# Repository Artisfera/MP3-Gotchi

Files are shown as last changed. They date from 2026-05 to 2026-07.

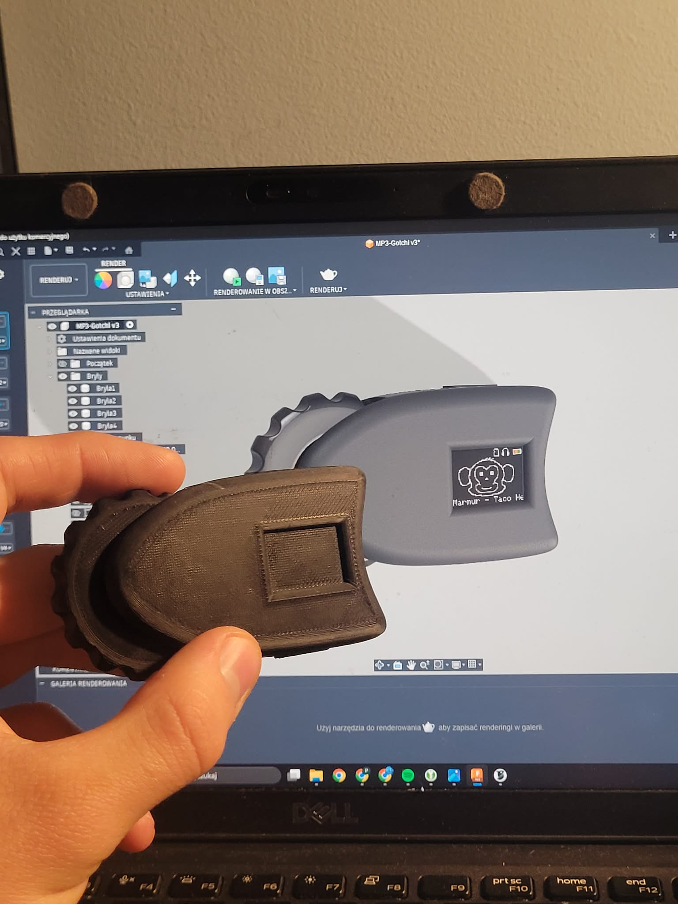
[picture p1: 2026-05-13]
hardware/3dmodels/0.1.0/Live-preview1-0.1.0.jpg

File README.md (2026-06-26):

# MP3-Gotchi

MP3-Gotchi is a tiny Tamagotchi-style offline MP3 player with a small monkey companion on a 96x64 color OLED.

The project is built around an ESP32, SSD1331 OLED, rotary encoder, YX5300 MP3 module, MPU6050 motion sensor, and haptic motor. It is shared as a community-source, source-available, non-commercial hardware and firmware project.

Current firmware release: `mp3gotchi-0.2.0`.

## Quick Start

Open the latest Arduino sketch here:

```text
firmware/src/mp3gotchi-0.2.0/mp3gotchi-0.2.0.ino
```

User-facing firmware settings live in:

```text
firmware/src/mp3gotchi-0.2.0/UserConfig.h
```

Start there for messages, track count, YX5300 track offset, volume, brightness, encoder steps, shake thresholds, and custom emote timing.

## Repository Layout

```text
firmware/assets/          Source sprite assets and sprite reference files.
firmware/src/             Latest Arduino sketch only.
firmware/reversions/      Historical firmware snapshots.
firmware/tools/           Community helper scripts for SD cards, fonts, and emotes.
firmware/user_emotes/     User workspace for custom emote layers.
hardware/3dmodels/        Enclosure exports by version.
hardware/drivers/         Driver download notes.
hardware/schematics/      Prototype schematic exports.
timelapses/               Prototype build videos and timelapse documentation.
```

## Firmware

The latest firmware uses:

- YX5300 UART playback,
- SSD1331 color OLED rendering,
- rotary encoder click and rotation controls,
- MPU6050 shake detection,
- haptic feedback,
- persistent ESP32 Preferences for track, volume, brightness, and shake settings,
- generated sparse RGB565 custom emotes,
- generated Aseprite Mini bitmap font data.

More firmware details are in `firmware/README.md` and the latest sketch README.

## Community Helpers

Prepare a YX5300 SD card in deterministic alphabetical copy order:

```powershell
python .\firmware\tools\prepare_yx5300_sd.py
```

Build custom emotes from full-screen PNG layers:

```powershell
py .\firmware\tools\user_emotes\build_user_emotes.py
```

Regenerate the Aseprite Mini font header from a local `.otf` file:

```powershell
python .\firmware\tools\generate_aseprite_mini_font.py --input C:\path\to\aseprite-mini.otf --output .\firmware\src\mp3gotchi-0.2.0\AsepriteMiniFontData.h --font-size 5
```

Local songs belong in `firmware/tools/songs/` while preparing an SD card. Real audio files are intentionally ignored by Git.

## Local Folders

`.git` is required by Git. It contains repository history, branches, and commit metadata. Do not delete it if you want commits to work.

`.venv` is a local Python virtual environment for helper scripts. It is useful on your machine but should not be committed.

`.backup` is local backup storage created during firmware work. It is ignored by Git.

## License and Use

MP3-Gotchi is shared for personal builds, learning, repair, modification, forks, and non-commercial community collaboration.

Commercial use is not allowed without written permission from Patryk Ankudowicz (Artisfera).

Because the project keeps a non-commercial restriction, it is not an OSI-approved open-source license. In public wording, prefer "community-source", "source-available", or "community-friendly non-commercial".

Firmware, helper scripts, and source code use the PolyForm Noncommercial License 1.0.0. Documentation, graphics, hardware files, models, schematics, videos, and media use CC BY-NC-SA 4.0 unless a file says otherwise. Third-party material is listed in `NOTICE`.

See `LICENSE` and `NON_COMMERCIAL_NOTICE.md`.

## AI Disclosure

Firmware and repository cleanup were prepared in collaboration with ChatGPT as a programming assistant.

The project concept, hardware direction, creative decisions, and authorship belong to Patryk Ankudowicz (Artisfera).

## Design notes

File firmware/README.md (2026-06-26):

# Firmware

The latest Arduino sketch is kept in `firmware/src/`.

For the current release, open:

```text
firmware/src/mp3gotchi-0.2.0/mp3gotchi-0.2.0.ino
```

Historical snapshots live in `firmware/reversions/`.

## Editing

Start with:

```text
firmware/src/mp3gotchi-0.2.0/UserConfig.h
```

This file is meant for community editing. It contains user-facing settings such as messages, default volume, brightness, track count, YX5300 index offset, encoder behavior, text scroll timing, shake thresholds, and custom emote timing.

Internal pin and firmware constants are kept in `ProjectConfig.h` and `PinMap.h`.

## Tools

- `tools/prepare_yx5300_sd.py` copies local songs to an SD card in deterministic alphabetical order.
- `tools/user_emotes/build_user_emotes.py` converts full-screen PNG layers into sparse RGB565 firmware assets.
- `tools/generate_aseprite_mini_font.py` generates the Aseprite Mini bitmap font header from a local `.otf` file.

Put local audio files in `tools/songs/` while preparing an SD card. The helper uses this folder by default no matter where it is launched from. The folder is ignored by Git except for its README.

## Arduino Libraries

Install these with Arduino IDE Library Manager:

- Adafruit SSD1331 OLED Driver Library
- Adafruit GFX Library

The MPU6050 is read through `Wire`.
The YX5300 module is controlled directly through UART frames.

## Versioning

`firmware/src/` contains the latest working sketch only.

`firmware/reversions/` keeps historical snapshots named like:

```text
mp3gotchi-0.1.13
mp3gotchi-0.2.0
```

The Arduino sketch folder name and `.ino` filename must match.

## License and Use

Firmware in this folder is part of MP3-Gotchi and follows the repository `LICENSE`.

It is community-source and source-available for personal building, learning, repair, modification, and non-commercial community collaboration.

Commercial use is not allowed without written permission from Patryk Ankudowicz (Artisfera).

Because the project keeps a non-commercial restriction, it is not OSI-approved open source. Prefer "community-source", "source-available", or "community-friendly non-commercial" in public wording.

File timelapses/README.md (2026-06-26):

# MP3-Gotchi Prototype Timelapses

This folder contains prototype build videos for MP3-Gotchi. They are documentation media for the project history and are not required to compile or flash the firmware.

Files:

- `1# MP3-Gotchi - Prototype 0.0.1.mp4`
- `2# MP3-Gotchi - Prototype.mp4`
- `3# MP3-Gotchi - Prototype.mp4`
- `4# MP3-Gotchi - Prototype.mp4`
- `5# MP3-Gotchi - Prototype.mp4`
- `6# MP3-Gotchi - Prototype.mp4`

Project concept, hardware direction, and authorship: Patryk Ankudowicz (Artisfera).

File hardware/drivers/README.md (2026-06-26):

# Drivers

Driver archives are not redistributed in this repository.

For CH341/CH340 USB-serial drivers, use the official WCH download page:

```text
https://www.wch-ic.com/downloads/CH341SER_EXE.html
```

This keeps third-party driver licensing separate from the MP3-Gotchi project license.

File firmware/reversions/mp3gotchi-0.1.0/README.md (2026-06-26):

# MP3-Gotchi firmware v0.1.0

This is the main firmware source for the MP3-Gotchi 0.1.0 prototype with a YX5300 audio module.
The code is meant to be copied into a project `src` folder and used as a clean base for later screens, tools, or small games.

## Features

- keeps `monkey-bg` as the static body/background layer,
- overlays face sprites for the normal and dizzy states,
- keeps the idle monkey visible when no special state is active,
- shows the dizzy face after a strong MPU6050 shake,
- pauses and resumes music with one encoder click,
- changes to the next track after the configured number of right encoder detents,
- restarts the current track on the first left action,
- moves to the previous track when the left action is repeated within the configured time window,
- enters ESP32 deep sleep after five encoder clicks,
- requires five clicks after a locked deep-sleep wake before the firmware starts playback again,
- can show a random weighted message in the bottom text strip after a track change.

## Arduino Libraries

Install these with Arduino IDE Library Manager:

- Adafruit SSD1331 OLED Driver Library
- Adafruit GFX Library
- Adafruit MPU6050
- Adafruit Unified Sensor

The YX5300 module is controlled directly through UART frames, so it does not need an external library.

## Pin Map

- OLED SCK: GPIO18
- OLED MOSI: GPIO23
- OLED RST: GPIO14
- OLED DC: GPIO13
- OLED CS: GPIO4
- YX5300 TX to ESP32 RX: GPIO17
- ESP32 TX to YX5300 RX through 1k: GPIO16
- Encoder A: GPIO27
- Encoder B: GPIO22
- Encoder SW: GPIO34, external 10k pull-up required
- Motor MOSFET gate: GPIO12
- MPU6050 SCL: GPIO5
- MPU6050 SDA: GPIO15
- MPU6050 INT: GPIO39
- Function 1 and Function 2 are reserved for future firmware and are not used in this version.

## Editing Bottom Messages

Edit the block in `MessagePool.cpp`:

```cpp
static const char MESSAGE_SCRIPT[] = R"MSG(
"Milego dnia!", 1.0;
"Dobry vibe", 0.8;
"Ziuu dalej", 0.7;
"Monkey mode", 1.2;
"Enjoy!";
"Shake me!", 0.5;
)MSG";
```

Format:

```cpp
"Text", 0.5;
"Text2";
"Text3", 1.2;
```

When no number is provided, the firmware uses weight `1.0`.
The number is a selection weight, not a percent. For example, `1.2` is more likely than `0.5`.

## Power Note

Five clicks do not physically disconnect the battery.
This firmware puts the ESP32 into deep sleep, tells the YX5300 to pause/sleep, blanks the OLED, and turns the motor output off.
A real hard power cut would need extra hardware such as a load switch, MOSFET latch, or physical switch.

## AI Disclosure

The `.ino` header intentionally says that the firmware was prepared in collaboration with ChatGPT as a programming assistant.
That note is part of the project process: the device concept, hardware decisions, and creative direction remain with the project author.

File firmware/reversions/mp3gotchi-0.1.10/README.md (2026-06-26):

# MP3-Gotchi firmware v0.1.10

This is the MP3-Gotchi 0.1.10 raw progress firmware. It keeps the working YX5300 and MPU6050 pinouts, adds logical YX5300 track mapping for the current module index offset, keeps user-generated emotes as generated sparse RGB565 assets, and keeps user-facing settings in one community-friendly file.

## Edit This First

Customize user settings in `UserConfig.h`.

That file contains:

- default YX5300 volume,
- default OLED brightness,
- logical YX5300 track count and module index offset,
- encoder detent thresholds,
- brightness encoder step,
- shake sensitivity,
- bottom text scroll speed,
- user emote timing and appearance chance,
- random bottom message chance,
- editable weighted message script.

## Features

- one click pauses/resumes playback,
- two clicks switches encoder mode between `Track`, `Volume`, and `Brightness`,
- five clicks enters ESP32 deep sleep,
- ten clicks resets playback to track 1,
- one encoder click wakes from deep sleep through GPIO34,
- track mode rotates through songs and keeps left-turn restart/previous behavior,
- volume mode changes YX5300 volume and saves it to ESP32 Preferences,
- brightness mode changes OLED brightness and saves it to ESP32 Preferences,
- Serial command `brightness 0-100` changes and saves OLED brightness,
- bottom messages scroll fully from offscreen left to offscreen right,
- bottom text is rendered with generated Aseprite Mini bitmap glyphs,
- custom user emotes can appear once per minute based on `UserConfig.h` chance settings,
- YX5300 finish events send the module `next` command instead of guessing a numeric track,
- MPU diagnostics default to the confirmed `SDA GPIO15 / SCL GPIO5` wiring,
- `mpu diag` prints 10 sensor samples over 10 seconds,
- `yx diag` prints raw module track and logical track mapping status.

## Font

The bottom text renderer uses `AsepriteMiniFontData.h`, generated from the real `aseprite-mini.otf` file supplied by the project author.
To regenerate it after replacing the font asset:

```powershell
.\.venv\Scripts\python.exe .\firmware\tools\generate_aseprite_mini_font.py --input C:\path\to\aseprite-mini.otf --output .\firmware\src\mp3gotchi-0.1.10\AsepriteMiniFontData.h --font-size 5
```

## Arduino Libraries

Install these with Arduino IDE Library Manager:

- Adafruit SSD1331 OLED Driver Library
- Adafruit GFX Library

The MPU6050 is read directly through `Wire`.
The YX5300 module is controlled directly through UART frames.

## Pin Map

- OLED SCK: GPIO18
- OLED MOSI: GPIO23
- OLED RST: GPIO14
- OLED DC: GPIO13
- OLED CS: GPIO4
- YX5300 TX to ESP32 RX: GPIO16
- ESP32 TX to YX5300 RX through 1k: GPIO17
- Encoder A: GPIO27
- Encoder B: GPIO22
- Encoder SW: GPIO34, external 10k pull-up required
- Motor MOSFET gate: GPIO12
- MPU6050 SDA: GPIO15
- MPU6050 SCL: GPIO5
- MPU6050 INT: GPIO39
- Function 1 and Function 2 are reserved for future firmware.

## Serial Commands

```text
pinout
brightness
brightness 0
brightness 50
brightness 100
mpu diag
yx diag
```

`mpu diag` reruns MPU detection and prints 10 accelerometer/gyro samples.
`yx diag` asks the module for current and total tracks, then prints raw module index, logical track, configured offset, and volume.

## Track Order

The ESP32 cannot alphabetically sort songs in this hardware layout because it talks only to the YX5300 over UART. It cannot see SD card filenames or directory entries.
Firmware uses YX5300 track commands and treats numeric track indexes as best-effort status only.

Normal next/previous navigation uses YX5300 module commands, because the module knows its own real track list and the ESP32 cannot read SD filenames through UART.
Absolute play commands use logical-to-module mapping from `UserConfig.h`.
With the current defaults, logical track `1` means file `001`, but the module command receives raw track index `2`.
If your module reports a different offset or track count, edit `USER_TRACK_COUNT` and `YX_TRACK_INDEX_OFFSET`.

## User Emotes

Put full-screen `96x64` PNG layers in `firmware/user_emotes/<emote-name>/`.
Use simple alphabetical prefixes when layer order matters:

```text
firmware/user_emotes/happy/
  01-eyes.png
  02-mouth.png
  03-nose.png
```

Run:

```powershell
py .\firmware\tools\user_emotes\build_user_emotes.py
```

The tool lists detected emote folders, asks which ones to build, asks for each emote weight and duration, writes `emote.png` previews, and generates `UserEmotes.h` in the latest sketch folder.
PNG is only the host-side input and preview format. The ESP32 firmware uses generated sparse RGB565 pixel data from `UserEmotes.h`.
Black pixels and transparent pixels are treated as empty space, matching the source sprite workflow.
Global timing and chance are in `UserConfig.h`:

```cpp
USER_EMOTE_APPEAR_CHANCE_PERCENT
USER_EMOTE_ROLL_INTERVAL_MS
USER_EMOTE_DEFAULT_SHOW_MS
```

For deterministic SD copy order, put your audio files in `firmware/tools/songs`, then run the friendly helper:

```powershell
python .\firmware\tools\prepare_yx5300_sd.py
```

It lists available drives with their size, asks you to pick the SD card by number, and then copies songs alphabetically.

## Power Note

Five clicks do not physically disconnect the battery.
This firmware puts the ESP32 into deep sleep, tells the YX5300 to pause/sleep, blanks the OLED, and turns the motor output off.
A real hard power cut needs extra hardware such as a load switch, MOSFET latch, or physical switch.

## License and Use

This project is community-friendly and source-available for personal, educational, repair, modification, and non-commercial collaboration.
Commercial use is not allowed without written permission from Patryk Ankudowicz (Artisfera).

See the repository `LICENSE` and `NON_COMMERCIAL_NOTICE.md`.

## AI Disclosure

The `.ino` header intentionally says that the firmware was prepared in collaboration with ChatGPT as a programming assistant.
The device concept, hardware decisions, and creative direction remain with the project author.

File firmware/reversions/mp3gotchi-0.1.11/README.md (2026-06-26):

# MP3-Gotchi firmware v0.1.11

This is the MP3-Gotchi 0.1.11 raw progress firmware. It keeps the working YX5300 and MPU6050 pinouts, keeps logical YX5300 track mapping, adds simple 1-100 shake sensitivity control, uses software OLED brightness scaling, and keeps user-facing settings in one community-friendly file.

## Edit This First

Customize user settings in `UserConfig.h`.

That file contains:

- default YX5300 volume,
- default OLED brightness,
- logical YX5300 track count and module index offset,
- encoder detent thresholds,
- brightness encoder step,
- shake sensitivity,
- bottom text scroll speed,
- user emote timing and appearance chance,
- random bottom message chance,
- editable weighted message script.

## Features

- one click pauses/resumes playback,
- two clicks switches encoder mode between `Track`, `Volume`, and `Brightness`,
- five clicks enters ESP32 deep sleep,
- ten clicks resets playback to track 1,
- one encoder click wakes from deep sleep through GPIO34,
- track mode rotates through songs and keeps left-turn restart/previous behavior,
- volume mode changes YX5300 volume and saves it to ESP32 Preferences,
- brightness mode changes OLED brightness and saves it to ESP32 Preferences,
- Serial command `brightness 0-100` changes and saves OLED brightness,
- Serial command `shake 1-100` changes and saves MPU6050 shake sensitivity,
- duplicated YX5300 track-finished packets are ignored so automatic playback does not skip every second track,
- bottom messages scroll fully from offscreen left to offscreen right,
- bottom text is rendered with generated Aseprite Mini bitmap glyphs,
- custom user emotes can appear once per minute based on `UserConfig.h` chance settings,
- YX5300 finish events send the module `next` command instead of guessing a numeric track,
- MPU diagnostics default to the confirmed `SDA GPIO15 / SCL GPIO5` wiring,
- `mpu diag` prints 10 sensor samples over 10 seconds,
- `yx diag` prints raw module track and logical track mapping status.

## Font

The bottom text renderer uses `AsepriteMiniFontData.h`, generated from the real `aseprite-mini.otf` file supplied by the project author.
To regenerate it after replacing the font asset:

```powershell
.\.venv\Scripts\python.exe .\firmware\tools\generate_aseprite_mini_font.py --input C:\path\to\aseprite-mini.otf --output .\firmware\src\mp3gotchi-0.1.11\AsepriteMiniFontData.h --font-size 5
```

## Arduino Libraries

Install these with Arduino IDE Library Manager:

- Adafruit SSD1331 OLED Driver Library
- Adafruit GFX Library

The MPU6050 is read directly through `Wire`.
The YX5300 module is controlled directly through UART frames.

## Pin Map

- OLED SCK: GPIO18
- OLED MOSI: GPIO23
- OLED RST: GPIO14
- OLED DC: GPIO13
- OLED CS: GPIO4
- YX5300 TX to ESP32 RX: GPIO16
- ESP32 TX to YX5300 RX through 1k: GPIO17
- Encoder A: GPIO27
- Encoder B: GPIO22
- Encoder SW: GPIO34, external 10k pull-up required
- Motor MOSFET gate: GPIO12
- MPU6050 SDA: GPIO15
- MPU6050 SCL: GPIO5
- MPU6050 INT: GPIO39
- Function 1 and Function 2 are reserved for future firmware.

## Serial Commands

```text
pinout
brightness
brightness 0
brightness 50
brightness 100
shake
shake 35
shake 80
mpu diag
yx diag
```

`brightness 0-100` changes the rendered pixel brightness and persists it.
`shake 1-100` changes shake sensitivity and persists it. `1` needs a hard shake, `100` reacts to light movement.
`mpu diag` reruns MPU detection and prints 10 accelerometer/gyro samples.
`yx diag` asks the module for current and total tracks, then prints raw module index, logical track, configured offset, and volume.

## Track Order

The ESP32 cannot alphabetically sort songs in this hardware layout because it talks only to the YX5300 over UART. It cannot see SD card filenames or directory entries.
Firmware uses YX5300 track commands and treats numeric track indexes as best-effort status only.

Normal next/previous navigation uses YX5300 module commands, because the module knows its own real track list and the ESP32 cannot read SD filenames through UART.
Absolute play commands use logical-to-module mapping from `UserConfig.h`.
With the current defaults, logical track `1` means file `001`, but the module command receives raw track index `2`.
If your module reports a different offset or track count, edit `USER_TRACK_COUNT` and `YX_TRACK_INDEX_OFFSET`.

## User Emotes

Put full-screen `96x64` PNG layers in `firmware/user_emotes/<emote-name>/`.
Use simple alphabetical prefixes when layer order matters:

```text
firmware/user_emotes/happy/
  01-eyes.png
  02-mouth.png
  03-nose.png
```

Run:

```powershell
py .\firmware\tools\user_emotes\build_user_emotes.py
```

The tool lists detected emote folders, asks which ones to build, asks for each emote weight and duration, writes `emote.png` previews, and generates `UserEmotes.h` in the latest sketch folder.
PNG is only the host-side input and preview format. The ESP32 firmware uses generated sparse RGB565 pixel data from `UserEmotes.h`.
Black pixels and transparent pixels are treated as empty space, matching the source sprite workflow.
Global timing and chance are in `UserConfig.h`:

```cpp
USER_EMOTE_APPEAR_CHANCE_PERCENT
USER_EMOTE_ROLL_INTERVAL_MS
USER_EMOTE_DEFAULT_SHOW_MS
```

For deterministic SD copy order, put your audio files in `firmware/tools/songs`, then run the friendly helper:

```powershell
python .\firmware\tools\prepare_yx5300_sd.py
```

It lists available drives with their size, asks you to pick the SD card by number, and then copies songs alphabetically.

## Power Note

Five clicks do not physically disconnect the battery.
This firmware puts the ESP32 into deep sleep, tells the YX5300 to pause/sleep, blanks the OLED, and turns the motor output off.
A real hard power cut needs extra hardware such as a load switch, MOSFET latch, or physical switch.

## License and Use

This project is community-friendly and source-available for personal, educational, repair, modification, and non-commercial collaboration.
Commercial use is not allowed without written permission from Patryk Ankudowicz (Artisfera).

See the repository `LICENSE` and `NON_COMMERCIAL_NOTICE.md`.

## AI Disclosure

The `.ino` header intentionally says that the firmware was prepared in collaboration with ChatGPT as a programming assistant.
The device concept, hardware decisions, and creative direction remain with the project author.

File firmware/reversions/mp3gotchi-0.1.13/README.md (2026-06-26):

# MP3-Gotchi firmware v0.1.13

This is the MP3-Gotchi 0.1.13 raw progress firmware. It keeps the working YX5300 and MPU6050 pinouts, keeps logical YX5300 track mapping, replaces the old artificial shake sensitivity scale with real MPU6050 thresholds, uses software OLED brightness scaling, and keeps user-facing settings in one community-friendly file.

## Edit This First

Customize user settings in `UserConfig.h`.

That file contains:

- default YX5300 volume,
- default OLED brightness,
- logical YX5300 track count and module index offset,
- encoder detent thresholds,
- brightness encoder step,
- shake detection thresholds,
- bottom text scroll speed,
- user emote timing and appearance chance,
- random bottom message chance,
- editable weighted message script.

## Features

- one click pauses/resumes playback,
- two clicks switches encoder mode between `Track`, `Volume`, and `Brightness`,
- five clicks enters ESP32 deep sleep,
- ten clicks resets playback to track 1,
- one encoder click wakes from deep sleep through GPIO34,
- track mode rotates through songs and keeps left-turn restart/previous behavior,
- volume mode changes YX5300 volume and saves it to ESP32 Preferences,
- brightness mode changes OLED brightness and saves it to ESP32 Preferences,
- Serial command `brightness 0-100` changes and saves OLED brightness,
- Serial command `shake` prints MPU6050 shake settings,
- Serial commands `shake hard`, `shake normal`, `shake light`, `shake verylight`, `shake off`, and `shake on` change and save shake profiles,
- Serial commands `shake total`, `shake change`, `shake gyro`, `shake confirm`, and `shake cooldown` fine tune shake detection and save it,
- Serial command `reboot` restarts the ESP32 firmware,
- duplicated YX5300 track-finished packets are ignored so automatic playback does not skip every second track,
- bottom text scroll updates only changed pixels to avoid visible blinking,
- bottom messages scroll fully from offscreen left to offscreen right,
- bottom text is rendered with generated Aseprite Mini bitmap glyphs,
- custom user emotes can appear once per minute based on `UserConfig.h` chance settings,
- YX5300 finish events send the module `next` command instead of guessing a numeric track,
- MPU diagnostics default to the confirmed `SDA GPIO15 / SCL GPIO5` wiring,
- `mpu diag` prints 10 sensor samples over 10 seconds,
- `yx diag` prints raw module track and logical track mapping status.

## Font

The bottom text renderer uses `AsepriteMiniFontData.h`, generated from the real `aseprite-mini.otf` file supplied by the project author.
To regenerate it after replacing the font asset:

```powershell
.\.venv\Scripts\python.exe .\firmware\tools\generate_aseprite_mini_font.py --input C:\path\to\aseprite-mini.otf --output .\firmware\src\mp3gotchi-0.1.13\AsepriteMiniFontData.h --font-size 5
```

## Arduino Libraries

Install these with Arduino IDE Library Manager:

- Adafruit SSD1331 OLED Driver Library
- Adafruit GFX Library

The MPU6050 is read directly through `Wire`.
The YX5300 module is controlled directly through UART frames.

## Pin Map

- OLED SCK: GPIO18
- OLED MOSI: GPIO23
- OLED RST: GPIO14
- OLED DC: GPIO13
- OLED CS: GPIO4
- YX5300 TX to ESP32 RX: GPIO16
- ESP32 TX to YX5300 RX through 1k: GPIO17
- Encoder A: GPIO27
- Encoder B: GPIO22
- Encoder SW: GPIO34, external 10k pull-up required
- Motor MOSFET gate: GPIO12
- MPU6050 SDA: GPIO15
- MPU6050 SCL: GPIO5
- MPU6050 INT: GPIO39
- Function 1 and Function 2 are reserved for future firmware.

## Serial Commands

```text
pinout
brightness
brightness 0
brightness 50
brightness 100
shake
shake hard
shake normal
shake light
shake verylight
shake off
shake on
shake total 0.85
shake change 0.50
shake gyro 360
shake confirm 2
shake cooldown 900
reboot
mpu diag
yx diag
```

`brightness 0-100` changes the rendered pixel brightness and persists it.
`shake` prints the current MPU6050 shake thresholds and command help.
The named shake profiles persist to flash. `hard` needs a very deliberate shake, `normal` is the default, `light` is easier, and `verylight` is intentionally sensitive.
Custom shake commands persist too:

- `shake total <g>` sets how far total acceleration must move away from normal gravity,
- `shake change <g>` sets the required frame-to-frame acceleration change,
- `shake gyro <dps>` sets the required rotation speed,
- `shake confirm <1-10>` sets how many consecutive strong samples are required,
- `shake cooldown <ms>` sets the delay after a detected shake.

`reboot` restarts the ESP32 firmware with `ESP.restart()`.
`mpu diag` reruns MPU detection and prints 10 accelerometer/gyro samples.
`yx diag` asks the module for current and total tracks, then prints raw module index, logical track, configured offset, and volume.

## Track Order

The ESP32 cannot alphabetically sort songs in this hardware layout because it talks only to the YX5300 over UART. It cannot see SD card filenames or directory entries.
Firmware uses YX5300 track commands and treats numeric track indexes as best-effort status only.

Normal next/previous navigation uses YX5300 module commands, because the module knows its own real track list and the ESP32 cannot read SD filenames through UART.
Absolute play commands use logical-to-module mapping from `UserConfig.h`.
With the current defaults, logical track `1` means file `001`, but the module command receives raw track index `2`.
If your module reports a different offset or track count, edit `USER_TRACK_COUNT` and `YX_TRACK_INDEX_OFFSET`.

## User Emotes

Put full-screen `96x64` PNG layers in `firmware/user_emotes/<emote-name>/`.
Use simple alphabetical prefixes when layer order matters:

```text
firmware/user_emotes/happy/
  01-eyes.png
  02-mouth.png
  03-nose.png
```

Run:

```powershell
py .\firmware\tools\user_emotes\build_user_emotes.py
```

The tool lists detected emote folders, asks which ones to build, asks for each emote weight and duration, writes `emote.png` previews, and generates `UserEmotes.h` in the latest sketch folder.
PNG is only the host-side input and preview format. The ESP32 firmware uses generated sparse RGB565 pixel data from `UserEmotes.h`.
Black pixels and transparent pixels are treated as empty space, matching the source sprite workflow.
Global timing and chance are in `UserConfig.h`:

```cpp
USER_EMOTE_APPEAR_CHANCE_PERCENT
USER_EMOTE_ROLL_INTERVAL_MS
USER_EMOTE_DEFAULT_SHOW_MS
```

For deterministic SD copy order, put your audio files in `firmware/tools/songs`, then run the friendly helper:

```powershell
python .\firmware\tools\prepare_yx5300_sd.py
```

It lists available drives with their size, asks you to pick the SD card by number, and then copies songs alphabetically.

## Power Note

Five clicks do not physically disconnect the battery.
This firmware puts the ESP32 into deep sleep, tells the YX5300 to pause/sleep, blanks the OLED, and turns the motor output off.
A real hard power cut needs extra hardware such as a load switch, MOSFET latch, or physical switch.

## License and Use

This project is community-friendly and source-available for personal, educational, repair, modification, and non-commercial collaboration.
Commercial use is not allowed without written permission from Patryk Ankudowicz (Artisfera).

See the repository `LICENSE` and `NON_COMMERCIAL_NOTICE.md`.

## AI Disclosure

The `.ino` header intentionally says that the firmware was prepared in collaboration with ChatGPT as a programming assistant.
The device concept, hardware decisions, and creative direction remain with the project author.

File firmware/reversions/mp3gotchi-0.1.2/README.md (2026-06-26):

# MP3-Gotchi firmware v0.1.2

This is the main firmware source for the MP3-Gotchi 0.1.2 prototype with a YX5300 audio module.
The code is meant to be copied into a project `src` folder and used as a clean base for later screens, tools, or small games.

## Features

- keeps `monkey-bg` as the static body/background layer,
- overlays face sprites for the normal and dizzy states,
- keeps the idle monkey visible when no special state is active,
- shows the dizzy face after a strong MPU6050 shake,
- pauses and resumes music with one encoder click,
- changes to the next track after the configured number of right encoder detents,
- restarts the current track on the first left action,
- moves to the previous track when the left action is repeated within the configured time window,
- enters ESP32 deep sleep after five encoder clicks,
- can show a random weighted message in the bottom text strip after a track change.
- includes temporary Serial Monitor pinout debug commands for MPU6050 and YX5300 wiring checks.

## Arduino Libraries

Install these with Arduino IDE Library Manager:

- Adafruit SSD1331 OLED Driver Library
- Adafruit GFX Library
- Adafruit MPU6050
- Adafruit Unified Sensor

The YX5300 module is controlled directly through UART frames, so it does not need an external library.

## Pin Map

- OLED SCK: GPIO18
- OLED MOSI: GPIO23
- OLED RST: GPIO14
- OLED DC: GPIO13
- OLED CS: GPIO4
- YX5300 TX to ESP32 RX: GPIO16
- ESP32 TX to YX5300 RX through 1k: GPIO17
- Encoder A: GPIO27
- Encoder B: GPIO22
- Encoder SW: GPIO34, external 10k pull-up required
- Motor MOSFET gate: GPIO12
- MPU6050 SDA: GPIO5
- MPU6050 SCL: GPIO15
- MPU6050 INT: GPIO39
- Function 1 and Function 2 are reserved for future firmware and are not used in this version.

## Editing Bottom Messages

Edit the block in `MessagePool.cpp`:

```cpp
static const char MESSAGE_SCRIPT[] = R"MSG(
"Milego dnia!", 1.0;
"Dobry vibe", 0.8;
"Ziuu dalej", 0.7;
"Monkey mode", 1.2;
"Enjoy!";
"Shake me!", 0.5;
)MSG";
```

Format:

```cpp
"Text", 0.5;
"Text2";
"Text3", 1.2;
```

When no number is provided, the firmware uses weight `1.0`.
The number is a selection weight, not a percent. For example, `1.2` is more likely than `0.5`.

## Power Note

Five clicks do not physically disconnect the battery.
This firmware puts the ESP32 into deep sleep, tells the YX5300 to pause/sleep, blanks the OLED, and turns the motor output off.
A real hard power cut would need extra hardware such as a load switch, MOSFET latch, or physical switch.

## Temporary Pinout Debug Commands

These Serial Monitor commands are temporary and should be removed after the hardware pinout is confirmed:

```text
pinout
odwroc mpu
odwroc yx
odwroc mpu/yx
```

`odwroc mpu` swaps SDA/SCL between `5/15` and `15/5`, then reruns MPU init.
`odwroc yx` swaps RX/TX between `16/17` and `17/16`, then sends volume plus play track 1.

## AI Disclosure

The `.ino` header intentionally says that the firmware was prepared in collaboration with ChatGPT as a programming assistant.
That note is part of the project process: the device concept, hardware decisions, and creative direction remain with the project author.

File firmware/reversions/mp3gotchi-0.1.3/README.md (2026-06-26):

# MP3-Gotchi firmware v0.1.3

This is the main firmware source for the MP3-Gotchi 0.1.3 prototype with a YX5300 audio module.
The code is meant to be copied into a project `src` folder and used as a clean base for later screens, tools, or small games.

## Features

- keeps `monkey-bg` as the static body/background layer,
- overlays face sprites for the normal and dizzy states,
- keeps the idle monkey visible when no special state is active,
- shows the dizzy face after a strong MPU6050 shake,
- pauses and resumes music with one encoder click,
- changes to the next track after the configured number of right encoder detents,
- restarts the current track on the first left action,
- moves to the previous track when the left action is repeated within the configured time window,
- enters ESP32 deep sleep after five encoder clicks,
- resets playback to track 1 after ten encoder clicks,
- remembers the last estimated track in ESP32 preferences before deep sleep,
- advances playback when the YX5300 reports that the current track ended,
- can show a random weighted message in the bottom text strip after a track change.
- includes temporary Serial Monitor pinout debug commands for MPU6050 and YX5300 wiring checks.

## Arduino Libraries

Install these with Arduino IDE Library Manager:

- Adafruit SSD1331 OLED Driver Library
- Adafruit GFX Library
- Adafruit MPU6050
- Adafruit Unified Sensor

The YX5300 module is controlled directly through UART frames, so it does not need an external library.
Playback uses global track numbers instead of folder-specific `001.mp3` naming rules.

## Pin Map

- OLED SCK: GPIO18
- OLED MOSI: GPIO23
- OLED RST: GPIO14
- OLED DC: GPIO13
- OLED CS: GPIO4
- YX5300 TX to ESP32 RX: GPIO16
- ESP32 TX to YX5300 RX through 1k: GPIO17
- Encoder A: GPIO27
- Encoder B: GPIO22
- Encoder SW: GPIO34, external 10k pull-up required
- Motor MOSFET gate: GPIO12
- MPU6050 SDA: GPIO5
- MPU6050 SCL: GPIO15
- MPU6050 INT: GPIO39
- Function 1 and Function 2 are reserved for future firmware and are not used in this version.

## Editing Bottom Messages

Edit the block in `MessagePool.cpp`:

```cpp
static const char MESSAGE_SCRIPT[] = R"MSG(
"Milego dnia!", 1.0;
"Dobry vibe", 0.8;
"Ziuu dalej", 0.7;
"Monkey mode", 1.2;
"Enjoy!";
"Shake me!", 0.5;
)MSG";
```

Format:

```cpp
"Text", 0.5;
"Text2";
"Text3", 1.2;
```

When no number is provided, the firmware uses weight `1.0`.
The number is a selection weight, not a percent. For example, `1.2` is more likely than `0.5`.

## Power Note

Five clicks do not physically disconnect the battery.
This firmware puts the ESP32 into deep sleep, tells the YX5300 to pause/sleep, blanks the OLED, and turns the motor output off.
A real hard power cut would need extra hardware such as a load switch, MOSFET latch, or physical switch.

## Temporary Pinout Debug Commands

These Serial Monitor commands are temporary and should be removed after the hardware pinout is confirmed:

```text
pinout
odwroc mpu
odwroc yx
odwroc mpu/yx
```

`odwroc mpu` swaps SDA/SCL between `5/15` and `15/5`, then reruns MPU init.
`odwroc yx` swaps RX/TX between `16/17` and `17/16`, then sends volume plus play track 1.
MPU init also auto-detects both pin orders and addresses `0x68` / `0x69`.

## Font

The bottom text strip uses an Aseprite Mini-compatible 3x5 bitmap renderer at 5 px height.

## AI Disclosure

The `.ino` header intentionally says that the firmware was prepared in collaboration with ChatGPT as a programming assistant.
That note is part of the project process: the device concept, hardware decisions, and creative direction remain with the project author.

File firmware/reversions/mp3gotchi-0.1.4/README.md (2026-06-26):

# MP3-Gotchi firmware v0.1.4

This is the MP3-Gotchi 0.1.4 raw progress firmware. It keeps the tested 0.1.3 behavior, leaves the working YX5300 pinout unchanged, and replaces the MPU6050 library path with a direct I2C driver that prints exact init stages.

## Features

- keeps `monkey-bg` as the static body/background layer,
- overlays normal and dizzy face sprites,
- pauses and resumes music with one encoder click,
- changes to the next track after the configured number of right encoder detents,
- restarts the current track on the first left action,
- moves to the previous track when the left action is repeated within the configured time window,
- waits for the full multi-click window so 10 clicks reset track 1 and do not trigger 5-click sleep,
- enters ESP32 deep sleep after five clicks,
- remembers the last estimated track before deep sleep,
- resumes the saved track after wake,
- resets and saves track 1 after ten clicks,
- uses raw MPU6050 I2C reads for shake detection,
- sends YX5300 loop-all fallback on boot and still logs finish packets if they arrive,
- scrolls the bottom message strip from left to right.

## Arduino Libraries

Install these with Arduino IDE Library Manager:

- Adafruit SSD1331 OLED Driver Library
- Adafruit GFX Library

The MPU6050 is read directly through `Wire`, so this version does not need the Adafruit MPU6050 or Adafruit Unified Sensor libraries.
The YX5300 module is controlled directly through UART frames, so it does not need an external audio library.

## Pin Map

- OLED SCK: GPIO18
- OLED MOSI: GPIO23
- OLED RST: GPIO14
- OLED DC: GPIO13
- OLED CS: GPIO4
- YX5300 TX to ESP32 RX: GPIO16
- ESP32 TX to YX5300 RX through 1k: GPIO17
- Encoder A: GPIO27
- Encoder B: GPIO22
- Encoder SW: GPIO34, external 10k pull-up required
- Motor MOSFET gate: GPIO12
- MPU6050 SDA: GPIO5
- MPU6050 SCL: GPIO15
- MPU6050 INT: GPIO39
- Function 1 and Function 2 are reserved for future firmware and are not used in this version.

## MPU6050 Debug

On boot the firmware tries both pin orders and both common MPU addresses:

- SDA GPIO5 / SCL GPIO15, addresses `0x68` and `0x69`
- SDA GPIO15 / SCL GPIO5, addresses `0x68` and `0x69`

For each attempt it reads `WHO_AM_I`, accepts `0x68`, `0x70`, and `0x71`, writes `PWR_MGMT_1 = 0x00`, and then reads raw accel/gyro bytes from `0x3B`.
Serial output names the exact failed stage: `address`, `WHO_AM_I`, `wake`, or `read sample`.

## Temporary Serial Commands

These commands are temporary and should be removed after the hardware pinout and YX behavior are confirmed:

```text
pinout
odwroc mpu
odwroc yx
odwroc mpu/yx
loop all on
loop all off
```

`odwroc mpu` swaps SDA/SCL between `5/15` and `15/5`, then reruns MPU init.
`odwroc yx` swaps RX/TX between `16/17` and `17/16`, then sends volume plus play track 1.
`loop all on` and `loop all off` send the YX5300 repeat-all fallback command.

## Track Order

The ESP32 cannot alphabetically sort songs in this hardware layout because it talks only to the YX5300 over UART. It cannot see SD card filenames or directory entries.
Firmware therefore uses global YX5300 track indexes.

For alphabetical playback without requiring `001`, `002`, `003` names, prepare an empty SD card from a sorted source folder:

```powershell
.\firmware\tools\prepare_yx5300_sd.ps1 -Source C:\Music\MP3Gotchi -Destination E:\
```

If your module or card still behaves unpredictably, use the stronger optional copy mode:

```powershell
.\firmware\tools\prepare_yx5300_sd.ps1 -Source C:\Music\MP3Gotchi -Destination E:\ -PrefixNumeric
```

The helper copies files one by one in alphabetical source order. Most YX5300-style modules play according to FAT directory order, so the SD card should be empty before copying.

## Editing Bottom Messages

Edit the block in `MessagePool.cpp`:

```cpp
static const char MESSAGE_SCRIPT[] = R"MSG(
"Milego dnia!", 1.0;
"Dobry vibe", 0.8;
"Ziuu dalej", 0.7;
"Monkey mode", 1.2;
"Enjoy!";
"Shake me!", 0.5;
)MSG";
```

Format:

```cpp
"Text", 0.5;
"Text2";
"Text3", 1.2;
```

When no number is provided, the firmware uses weight `1.0`.
The number is a selection weight, not a percent. For example, `1.2` is more likely than `0.5`.

## Font

The current firmware still contains `TinyFont5` as a temporary fallback so the sketch stays buildable.
It is not claimed to be Aseprite Mini.

To use the real Aseprite Mini font, supply your own licensed PNG sheet and generate a header named `AsepriteMiniFontData.h`:

```powershell
python .\firmware\tools\generate_aseprite_mini_font.py --input C:\Fonts\aseprite-mini.png --output .\firmware\src\mp3gotchi-0.1.4\AsepriteMiniFontData.h
```

After the generated header is available, replace the fallback renderer with the generated glyph table.

## Power Note

Five clicks do not physically disconnect the battery.
This firmware puts the ESP32 into deep sleep, tells the YX5300 to pause/sleep, blanks the OLED, and turns the motor output off.
A real hard power cut would need extra hardware such as a load switch, MOSFET latch, or physical switch.

## AI Disclosure

The `.ino` header intentionally says that the firmware was prepared in collaboration with ChatGPT as a programming assistant.
That note is part of the project process: the device concept, hardware decisions, and creative direction remain with the project author.

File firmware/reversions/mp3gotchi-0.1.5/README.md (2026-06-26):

# MP3-Gotchi firmware v0.1.5

This is the MP3-Gotchi 0.1.5 raw progress firmware. It keeps the working YX5300 UART pinout, adds stronger MPU6050 diagnostics, fixes end-of-track playback, adds OLED brightness control, and moves user-facing settings into one community-friendly file.

## Edit This First

Customize user settings in `UserConfig.h`.

That file contains:

- default YX5300 volume,
- default OLED brightness,
- known track count for wrap-to-track-1,
- encoder detent thresholds,
- bottom text scroll speed,
- random bottom message chance,
- editable weighted message script.

## Features

- one click pauses/resumes playback,
- two clicks switches encoder mode between `TRACK` and `VOLUME`,
- five clicks enters ESP32 deep sleep,
- ten clicks resets playback to track 1,
- one encoder click wakes from deep sleep through GPIO34,
- track mode rotates through songs and keeps left-turn restart/previous behavior,
- volume mode changes YX5300 volume and saves it to ESP32 Preferences,
- Serial command `brightness 0-100` changes and saves OLED brightness,
- bottom messages scroll fully from offscreen left to offscreen right,
- YX5300 finish events explicitly start the next track,
- MPU diagnostics try both pin orders, addresses `0x68/0x69`, and I2C speeds `100k/50k/400k`.

## Arduino Libraries

Install these with Arduino IDE Library Manager:

- Adafruit SSD1331 OLED Driver Library
- Adafruit GFX Library

The MPU6050 is read directly through `Wire`.
The YX5300 module is controlled directly through UART frames.

## Pin Map

- OLED SCK: GPIO18
- OLED MOSI: GPIO23
- OLED RST: GPIO14
- OLED DC: GPIO13
- OLED CS: GPIO4
- YX5300 TX to ESP32 RX: GPIO16
- ESP32 TX to YX5300 RX through 1k: GPIO17
- Encoder A: GPIO27
- Encoder B: GPIO22
- Encoder SW: GPIO34, external 10k pull-up required
- Motor MOSFET gate: GPIO12
- MPU6050 SDA: GPIO5
- MPU6050 SCL: GPIO15
- MPU6050 INT: GPIO39
- Function 1 and Function 2 are reserved for future firmware.

## Serial Commands

```text
pinout
brightness
brightness 0
brightness 50
brightness 100
mpu diag
mpu scan
mpu pins <sda> <scl>
odwroc mpu
odwroc yx
odwroc mpu/yx
loop all on
loop all off
```

`mpu diag` reruns full MPU detection.
`mpu scan` scans I2C on the active and swapped pin orders.
`mpu pins <sda> <scl>` lets you test a manual pin pair.
`loop all` commands are kept only as temporary YX5300 hardware debug helpers; normal firmware uses explicit next-track play commands.

## Track Order

The ESP32 cannot alphabetically sort songs in this hardware layout because it talks only to the YX5300 over UART. It cannot see SD card filenames or directory entries.
Firmware uses global YX5300 track indexes.

Set `USER_TRACK_COUNT` in `UserConfig.h` if you know how many tracks are on the SD card. When it is `0`, firmware advances upward without wrap-to-1.

For deterministic SD copy order, put your audio files in `firmware/tools/songs`, then run the friendly helper:

```powershell
python .\firmware\tools\prepare_yx5300_sd.py
```

It lists available drives with their size, asks you to pick the SD card by number, and then copies songs alphabetically.

## Power Note

Five clicks do not physically disconnect the battery.
This firmware puts the ESP32 into deep sleep, tells the YX5300 to pause/sleep, blanks the OLED, and turns the motor output off.
A real hard power cut needs extra hardware such as a load switch, MOSFET latch, or physical switch.

## License and Use

This project is community-friendly and source-available for personal, educational, repair, modification, and non-commercial collaboration.
Commercial use is not allowed without written permission from Patryk Ankudowicz (Artisfera).

See the repository `LICENSE` and `NON_COMMERCIAL_NOTICE.md`.

## AI Disclosure

The `.ino` header intentionally says that the firmware was prepared in collaboration with ChatGPT as a programming assistant.
The device concept, hardware decisions, and creative direction remain with the project author.

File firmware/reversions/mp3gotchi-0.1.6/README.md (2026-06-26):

# MP3-Gotchi firmware v0.1.6

This is the MP3-Gotchi 0.1.6 raw progress firmware. It keeps the working YX5300 UART pinout, uses YX5300 module-relative next/previous commands for normal navigation, keeps stronger MPU6050 diagnostics, and keeps user-facing settings in one community-friendly file.

## Edit This First

Customize user settings in `UserConfig.h`.

That file contains:

- default YX5300 volume,
- default OLED brightness,
- reserved track count setting,
- encoder detent thresholds,
- bottom text scroll speed,
- random bottom message chance,
- editable weighted message script.

## Features

- one click pauses/resumes playback,
- two clicks switches encoder mode between `TRACK` and `VOLUME`,
- five clicks enters ESP32 deep sleep,
- ten clicks resets playback to track 1,
- one encoder click wakes from deep sleep through GPIO34,
- track mode rotates through songs and keeps left-turn restart/previous behavior,
- volume mode changes YX5300 volume and saves it to ESP32 Preferences,
- Serial command `brightness 0-100` changes and saves OLED brightness,
- bottom messages scroll fully from offscreen left to offscreen right,
- YX5300 finish events send the module `next` command instead of guessing a numeric track,
- MPU diagnostics try both pin orders, addresses `0x68/0x69`, and I2C speeds `100k/50k/400k`.

## Arduino Libraries

Install these with Arduino IDE Library Manager:

- Adafruit SSD1331 OLED Driver Library
- Adafruit GFX Library

The MPU6050 is read directly through `Wire`.
The YX5300 module is controlled directly through UART frames.

## Pin Map

- OLED SCK: GPIO18
- OLED MOSI: GPIO23
- OLED RST: GPIO14
- OLED DC: GPIO13
- OLED CS: GPIO4
- YX5300 TX to ESP32 RX: GPIO16
- ESP32 TX to YX5300 RX through 1k: GPIO17
- Encoder A: GPIO27
- Encoder B: GPIO22
- Encoder SW: GPIO34, external 10k pull-up required
- Motor MOSFET gate: GPIO12
- MPU6050 SDA: GPIO5
- MPU6050 SCL: GPIO15
- MPU6050 INT: GPIO39
- Function 1 and Function 2 are reserved for future firmware.

## Serial Commands

```text
pinout
brightness
brightness 0
brightness 50
brightness 100
mpu diag
mpu scan
mpu pins <sda> <scl>
yx query
odwroc mpu
odwroc yx
odwroc mpu/yx
loop all on
loop all off
```

`mpu diag` reruns full MPU detection.
`mpu scan` scans I2C on the active and swapped pin orders.
`mpu pins <sda> <scl>` lets you test a manual pin pair.
`yx query` asks the module for current track and total track count. Some YX5300-compatible boards answer, some do not.
`loop all` commands are kept only as temporary YX5300 hardware debug helpers; normal firmware uses the module `next` command.

## Track Order

The ESP32 cannot alphabetically sort songs in this hardware layout because it talks only to the YX5300 over UART. It cannot see SD card filenames or directory entries.
Firmware uses YX5300 track commands and treats numeric track indexes as best-effort status only.

Normal next/previous navigation uses YX5300 module commands, because the module knows its own real track list and the ESP32 cannot read SD filenames through UART.
If an older firmware saved an invalid track number, `0.1.6` tries to repair it when the module answers the total-track query.

For deterministic SD copy order, put your audio files in `firmware/tools/songs`, then run the friendly helper:

```powershell
python .\firmware\tools\prepare_yx5300_sd.py
```

It lists available drives with their size, asks you to pick the SD card by number, and then copies songs alphabetically.

## Power Note

Five clicks do not physically disconnect the battery.
This firmware puts the ESP32 into deep sleep, tells the YX5300 to pause/sleep, blanks the OLED, and turns the motor output off.
A real hard power cut needs extra hardware such as a load switch, MOSFET latch, or physical switch.

## License and Use

This project is community-friendly and source-available for personal, educational, repair, modification, and non-commercial collaboration.
Commercial use is not allowed without written permission from Patryk Ankudowicz (Artisfera).

See the repository `LICENSE` and `NON_COMMERCIAL_NOTICE.md`.

## AI Disclosure

The `.ino` header intentionally says that the firmware was prepared in collaboration with ChatGPT as a programming assistant.
The device concept, hardware decisions, and creative direction remain with the project author.

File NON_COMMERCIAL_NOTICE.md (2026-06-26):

# Non-Commercial Project Notice

MP3-Gotchi is shared as a community-source, source-available project for personal building, learning, repair, modification, and non-commercial collaboration.

Commercial use is not allowed without written permission from Patryk Ankudowicz (Artisfera). This includes selling devices, kits, firmware, hardware files, sprites, branding, paid derivatives, or using the project in commercial client work or campaigns.

Because the project keeps a non-commercial restriction, it should not be described as OSI-approved open source. Use "community-source", "source-available", or "community-friendly non-commercial" unless a separate written license says otherwise.

This repository uses standard license texts:

- firmware, helper scripts, and source code: PolyForm Noncommercial License 1.0.0;
- documentation, graphics, hardware files, models, schematics, videos, and media: CC BY-NC-SA 4.0;
- third-party material: see `NOTICE`.

See `LICENSE` for the full license map.

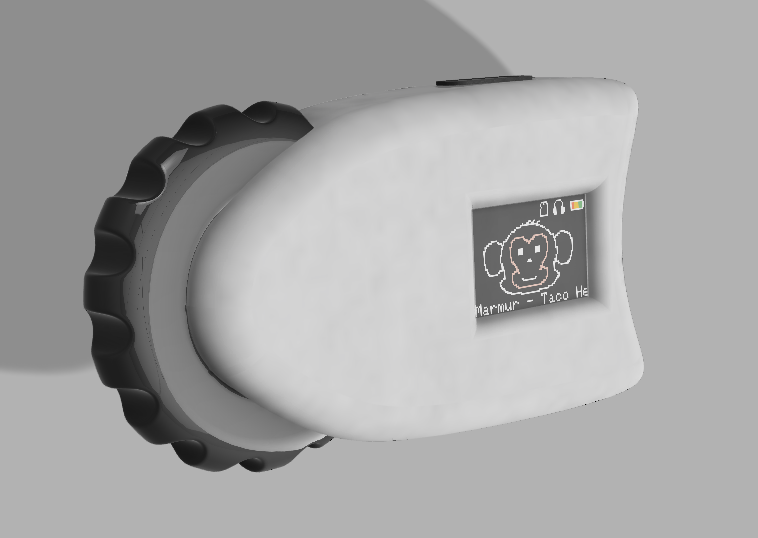
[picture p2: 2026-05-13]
hardware/3dmodels/0.1.0/Preview1-0.1.0.png

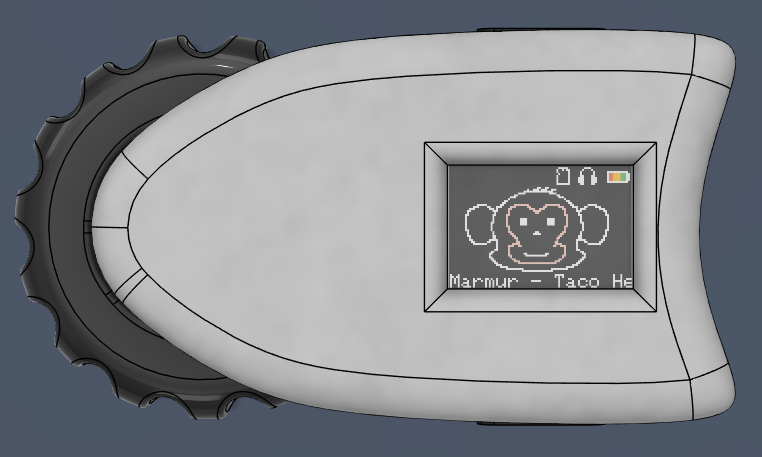
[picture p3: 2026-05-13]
hardware/3dmodels/0.1.0/Preview2-0.1.0.png

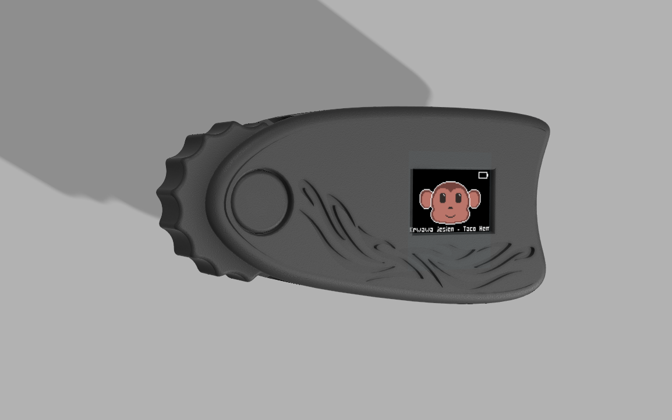
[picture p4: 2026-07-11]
hardware/3dmodels/0.3.0/MP3-Gotchi-0.3.0.png

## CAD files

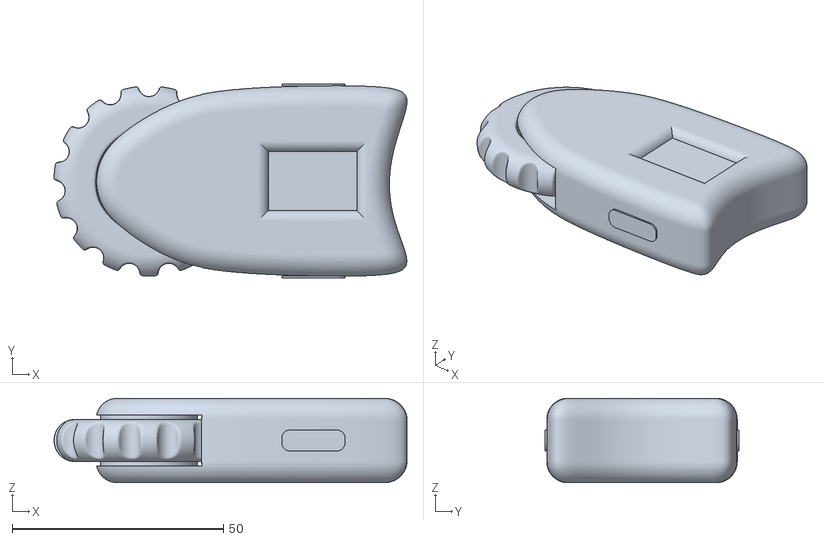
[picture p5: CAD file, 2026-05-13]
hardware/3dmodels/0.1.0/MP3-Gotchi-0.1.0.stl
83.6 x 45.9 x 20.0

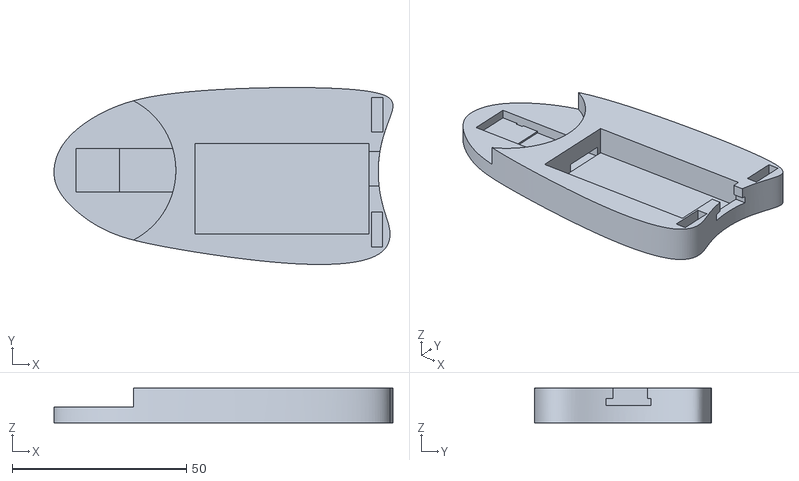
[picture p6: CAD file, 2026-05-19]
hardware/3dmodels/0.2.1/MP3-Gotchi-0.2.1.stl
97.4 x 50.8 x 10.0

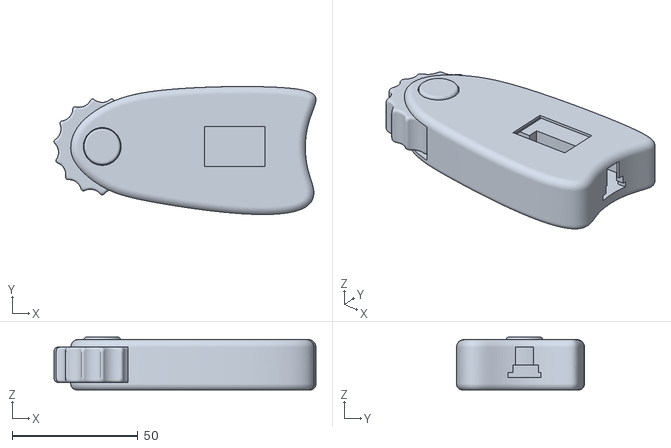
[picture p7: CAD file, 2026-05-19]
hardware/3dmodels/0.2.3/MP3-Gotchi-0.2.3.stl
104.0 x 50.8 x 21.0

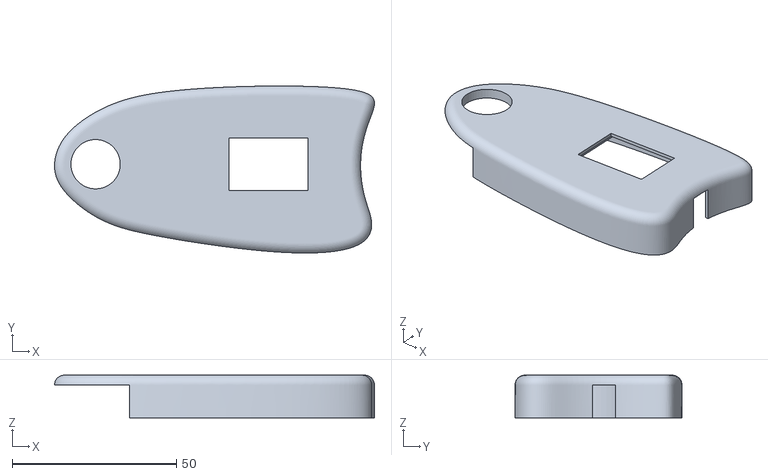
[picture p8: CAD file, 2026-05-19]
hardware/3dmodels/0.2.4/MP3-Gotchi-0.2.4.stl
97.4 x 50.8 x 13.0

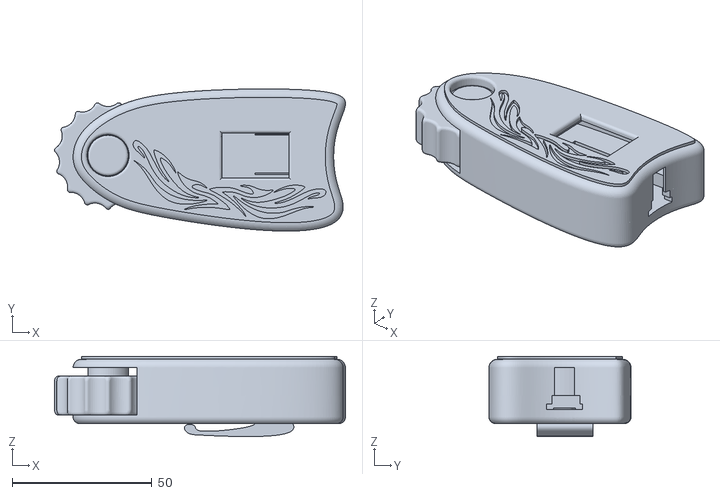
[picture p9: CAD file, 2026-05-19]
hardware/3dmodels/0.2.5/MP3-Gotchi-0.2.5.stl
104.0 x 50.8 x 28.6

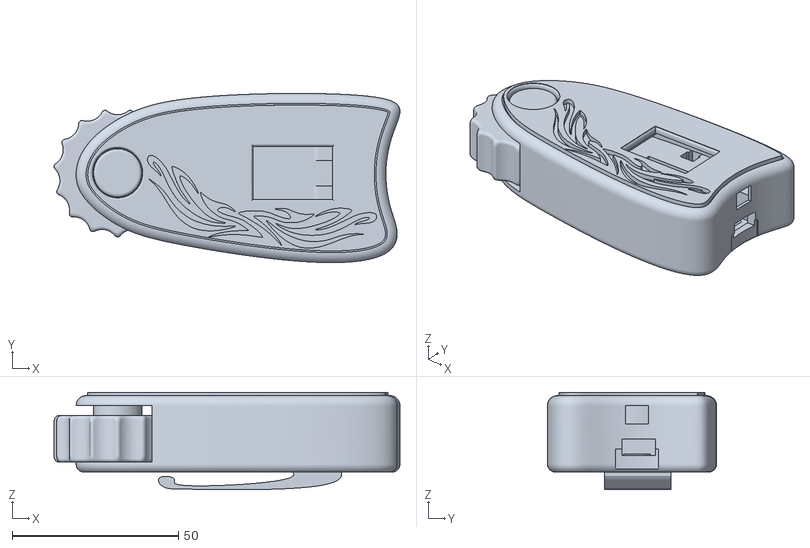
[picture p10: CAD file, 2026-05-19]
hardware/3dmodels/0.3.0/MP3-Gotchi-0.3.0.stl
104.0 x 50.9 x 29.3

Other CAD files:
hardware/3dmodels/0.2.2/MP3-Gotchi-0.2.2.stl
hardware/3dmodels/0.2.3/MP3-Gotchi-0.2.3.f3d
hardware/3dmodels/0.3.0/MP3-Gotchi-0.3.0.dxf

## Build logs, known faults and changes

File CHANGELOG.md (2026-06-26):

# Changelog

## 0.2.0

- Promoted the working firmware from `0.1.13` to `0.2.0`.
- Kept `firmware/src/` focused on the latest Arduino sketch.
- Documented the YX5300-based firmware workflow.
- Added community cleanup notes for local songs, Python caches, Arduino build outputs, backups, and local virtual environments.

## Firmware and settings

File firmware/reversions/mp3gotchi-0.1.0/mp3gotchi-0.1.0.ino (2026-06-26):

/*
  MP3-Gotchi firmware v0.1.0

  Concept, hardware direction and project decisions: Patryk Ankudowicz (Artisfera).
  Firmware implementation prepared in collaboration with ChatGPT as programming assistant.

  This note is intentional. The project is source-available non-commercial and does not hide that AI was used
  as a coding partner. The device concept, build decisions and creative direction stay with
  the project author.
*/

#include "App.h"

App app;

void setup() {
  app.begin();
}

void loop() {
  app.loop();
}

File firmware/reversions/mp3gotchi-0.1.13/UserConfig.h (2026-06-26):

#pragma once
#include <Arduino.h>

// MP3-Gotchi user-editable settings.
// Start here when customizing the community firmware.

namespace UserConfig {
  constexpr uint8_t DEFAULT_VOLUME = 18;       // YX5300 volume range: 0..30.
  constexpr uint8_t DEFAULT_BRIGHTNESS = 100;  // OLED brightness percent: 0..100.
  constexpr uint16_t USER_TRACK_COUNT = 4;     // Set to 0 if the module track count is unknown.
  constexpr uint16_t YX_TRACK_INDEX_OFFSET = 1; // Logical 001 maps to module track 2 on the current hardware.

  constexpr int ENCODER_TRANSITIONS_PER_DETENT = 4;
  constexpr int TRACK_CHANGE_DETENTS = 5;
  constexpr int VOLUME_CHANGE_DETENTS = 1;
  constexpr int BRIGHTNESS_CHANGE_DETENTS = 1;
  constexpr uint8_t BRIGHTNESS_CHANGE_STEP_PERCENT = 5;
  constexpr unsigned long PREVIOUS_SECOND_TURN_WINDOW_MS = 2500;

  constexpr uint8_t MESSAGE_APPEAR_CHANCE_PERCENT = 65;
  constexpr unsigned long MESSAGE_SHOW_MS = 4200;
  constexpr uint8_t MAX_MESSAGES = 20;
  constexpr unsigned long TEXT_SCROLL_FRAME_MS = 80;
  constexpr int16_t TEXT_SCROLL_STEP_PX = 1;

  constexpr bool USER_EMOTES_ENABLED = true;
  constexpr uint8_t USER_EMOTE_APPEAR_CHANCE_PERCENT = 35;
  constexpr unsigned long USER_EMOTE_ROLL_INTERVAL_MS = 60000;
  constexpr unsigned long USER_EMOTE_DEFAULT_SHOW_MS = 2400;

  constexpr bool SHAKE_ENABLED = true;
  constexpr float SHAKE_ACCEL_TOTAL_G_THRESHOLD = 0.85f;   // Required total-g difference from normal gravity.
  constexpr float SHAKE_ACCEL_CHANGE_G_THRESHOLD = 0.50f;  // Required frame-to-frame total-g change.
  constexpr float SHAKE_GYRO_DPS_THRESHOLD = 360.0f;       // Required rotation speed in degrees per second.
  constexpr uint8_t SHAKE_CONFIRM_SAMPLES = 2;             // Consecutive strong samples before a shake is accepted.
  constexpr unsigned long SHAKE_COOLDOWN_MS = 900;         // Delay after a detected shake.

  static const char MESSAGE_SCRIPT[] = R"MSG(
"Milego dnia", 1.0;
"Dobry vibe", 0.8;
"Ziuu dalej", 0.7;
"Monkey mode", 1.2;
"Enjoy";
"Shake me", 0.5;
)MSG";
}

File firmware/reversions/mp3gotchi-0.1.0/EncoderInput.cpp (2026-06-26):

#include "EncoderInput.h"
#include "PinMap.h"
#include "ProjectConfig.h"

void EncoderInput::begin() {
  pinMode(Pins::ENCODER_A, INPUT_PULLUP);
  pinMode(Pins::ENCODER_B, INPUT_PULLUP);
  pinMode(Pins::ENCODER_SW, INPUT);
  lastAB = (digitalRead(Pins::ENCODER_A) << 1) | digitalRead(Pins::ENCODER_B);
}

InputEvents EncoderInput::update() {
  InputEvents events;
  events.rotationDetents = readRotationDetents();
  events.clickCount = readButtonClicks(events.longPress);
  return events;
}

int8_t EncoderInput::readRotationDetents() {
  static const int8_t table[16] = {
    0, -1,  1,  0,
    1,  0,  0, -1,
   -1,  0,  0,  1,
    0,  1, -1,  0
  };

  uint8_t ab = (digitalRead(Pins::ENCODER_A) << 1) | digitalRead(Pins::ENCODER_B);
  uint8_t index = (lastAB << 2) | ab;
  lastAB = ab;

  int8_t delta = table[index & 0x0F];
  if (delta == 0) return 0;

  transitionAccum += delta;

  if (transitionAccum >= Config::ENCODER_TRANSITIONS_PER_DETENT) {
    transitionAccum = 0;
    return 1;
  }

  if (transitionAccum <= -Config::ENCODER_TRANSITIONS_PER_DETENT) {
    transitionAccum = 0;
    return -1;
  }

  return 0;
}

uint8_t EncoderInput::readButtonClicks(bool& longPressOut) {
  longPressOut = false;
  uint8_t emittedClicks = 0;
  bool raw = digitalRead(Pins::ENCODER_SW);
  unsigned long now = millis();

  if (raw != lastRawButton) {
    lastRawButton = raw;
    lastDebounceMs = now;
  }

  if ((now - lastDebounceMs) > Config::DEBOUNCE_MS && raw != stableButton) {
    stableButton = raw;

    if (stableButton == LOW) {
      pressedAtMs = now;
      longPressSent = false;
    } else {
      if (!longPressSent) {
        pendingClicks++;
        lastReleaseMs = now;
      }
    }
  }

  if (stableButton == LOW && !longPressSent && (now - pressedAtMs) >= Config::LONG_PRESS_MS) {
    longPressSent = true;
    pendingClicks = 0;
    longPressOut = true;
  }

  if (pendingClicks > 0 && (now - lastReleaseMs) >= Config::MULTI_CLICK_GAP_MS) {
    emittedClicks = pendingClicks;
    pendingClicks = 0;
  }

  return emittedClicks;
}

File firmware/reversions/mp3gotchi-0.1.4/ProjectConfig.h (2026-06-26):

#pragma once

// MP3-Gotchi firmware v0.1.4 configuration.
// Project concept and hardware by Patryk Ankudowicz (Artisfera).
// Firmware created in collaboration with ChatGPT as programming assistant.

namespace Config {
  constexpr int SERIAL_BAUD = 115200;

  constexpr bool AUTOPLAY_ON_BOOT = true;
  constexpr uint8_t START_FOLDER = 1;
  constexpr uint16_t START_TRACK = 1;
  constexpr uint8_t DEFAULT_VOLUME = 18;       // YX5300 range is normally 0..30.

  constexpr int ENCODER_TRANSITIONS_PER_DETENT = 4;
  constexpr int TRACK_CHANGE_DETENTS = 5;      // Rotate this many detents to change track.
  constexpr unsigned long PREVIOUS_SECOND_TURN_WINDOW_MS = 2500;
  constexpr uint16_t TRACK_LOOP_LAST_TRACK = 0; // 0 means unknown: use module next/previous commands.
  constexpr bool YX_DEBUG_PACKETS = true;
  constexpr bool YX_ENABLE_LOOP_ALL_FALLBACK = true;

  constexpr unsigned long MULTI_CLICK_GAP_MS = 320;
  constexpr unsigned long DEBOUNCE_MS = 35;
  constexpr unsigned long LONG_PRESS_MS = 850;
  constexpr uint8_t SLEEP_CLICK_COUNT = 5;
  constexpr uint8_t RESET_TRACK_CLICK_COUNT = 10;

  constexpr float SHAKE_ACCEL_DELTA_THRESHOLD = 1.0f;  // m/s^2 above or below gravity.
  constexpr float SHAKE_ACCEL_CHANGE_THRESHOLD = 0.45f; // m/s^2 between sensor samples.
  constexpr float SHAKE_GYRO_THRESHOLD = 0.65f;         // rad/s combined rotation.
  constexpr unsigned long SHAKE_COOLDOWN_MS = 350;
  constexpr unsigned long DIZZY_DURATION_MS = 2200;

  constexpr unsigned long IDLE_FRAME_MS = 650;
  constexpr unsigned long MUSIC_FRAME_MS = 430;
  constexpr unsigned long DIZZY_FRAME_MS = 180;
  constexpr unsigned long BLINK_EVERY_MIN_MS = 3500;
  constexpr unsigned long BLINK_EVERY_MAX_MS = 7200;
  constexpr unsigned long BLINK_DURATION_MS = 140;

  constexpr uint8_t MESSAGE_APPEAR_CHANCE_PERCENT = 65;
  constexpr unsigned long MESSAGE_SHOW_MS = 4200;
  constexpr uint8_t MAX_MESSAGES = 20;
  constexpr unsigned long TEXT_SCROLL_FRAME_MS = 80;
  constexpr int16_t TEXT_SCROLL_STEP_PX = 1;

  constexpr bool DRAW_STATIC_SDCARD_ICON = false;
  constexpr bool DRAW_STATIC_HEADPHONES_ICON = false;
  constexpr bool DRAW_BATTERY_ICON = false; // No battery ADC in current hardware revision.
  constexpr bool DRAW_PLAYING_INDICATOR = false;
}

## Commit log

2026-05-13 Replace stasis BOM with 0.3.0 BOM
    Remove the old stasis-bom.csv and add a new hardware/bom/0.3.0-bom.csv for the prototype. The new BOM lists parts for the MP3-Gotchi prototype (LoLin ESP32 Wemos Lite, SSD1331 OLED, rotary encoder, SPI microSD reader, MPU6050, vibration motors, reused LiPo, wired earphones, and shipping), replacing the previous ATTINY-based stasis bill of materials.
    [0.3.0-bom.csv, stasis-bom.csv]
2026-05-19 Add 3D models, sprite assets, and CH341 BOM
    Add release artifacts and assets: multiple MP3-Gotchi 3D files (STL/F3D) for versions 0.2.1 through 0.3.0, new firmware sprite assets (Aseprite and PNG) including monkey-brains-8x, and a hardware BOM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
    [MP3-Gotchi-0.2.1.stl, MP3-Gotchi-0.2.2.stl, MP3-Gotchi-0.2.3.f3d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]
2026-06-26 MP3-Gotchi - Prototype
    Import firmware tree, assets and project metadata: add firmware/ with sprite assets (Eyes, Mouths, HUD, Icons, Noses), Aseprite source, MP3-Gotchi GUI, and a large set of versioned firmware snapshots under firmware/reversions (multiple mp3gotchi-x.y.z releases and source_sprites). Add project docs and policy files: .gitignore, CHANGELOG.md, CONTRIBUTING.md, NON_COMMERCIAL_NOTICE.md, NOTICE, LICENSES/* and firmware/README.md. Update .gitattributes, LICENSE and README.md. Remove obsolete image files and a few old firmware sprites that were deleted.
    [0.3.0-bom.csv, MP3-Gotchi-0.2.1.stl, MP3-Gotchi-0.2.2.stl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]
